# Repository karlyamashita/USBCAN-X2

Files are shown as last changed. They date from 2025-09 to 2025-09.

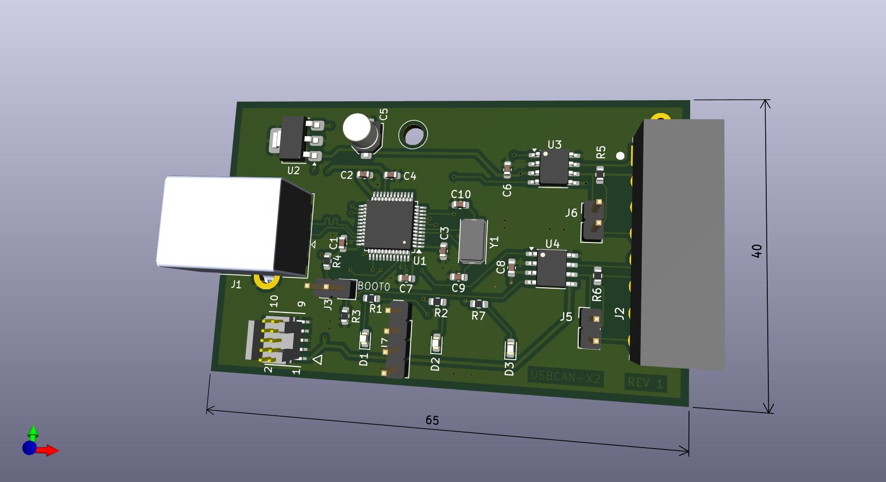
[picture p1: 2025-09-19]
Images/USBCAN-X2.jpg

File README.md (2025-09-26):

USBCAN-X2 dual CAN bus analyzer using a STM32G491CE.

The schematic and gerber files are open source.

### Description
I have been working on a [CAN Jammer](https://github.com/karlyamashita/CAN_Jammer_STM32F105RB) project and need a dual CAN bus analyzer that uses 1 STM32 microcontroller. I am finding it difficult to find a vendor that sells a dual CAN bus analyzer that uses an STM32 that is open source and does not read protect the STM32 at RDP level 2. Most vendors that i've contacted are using NXP or a Chinese brand microcontroller. 
<br><br>
Because of the difficulties of finding a dual CAN bus analyzer, I've decided to create this open source project. Since FDCAN is becoming more mainstream, I've decided to use the STM32G491CE with FDCAN controllers which meet the requirements. 

### PCB
The PBC was designed around the USBCAN-2A, matching the USB and screw terminal connector. I am hoping some Chinese manufacturer or someone local will start to manufacture this project to make readily available for purchase. Since the plastic case seems to be a dime a dozen, it will make it easier fo manufacturers to have a completely enclosed product without the need to tool for a new case, if I did create a different size PCB.

`USBCAN-2A`


### Firmware
The FW is being developed and will be open source.

### Software
CAN-X will support the USBCAN-X2 once the Firmware is done.

### Image
This is the 3D image of the USBCAN-X2

`USBCAN-X2`


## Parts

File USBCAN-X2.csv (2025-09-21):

Reference | Qty | Value | DNP | Exclude from BOM | Exclude from Board | Footprint | Datasheet | Mouser
C1,C2,C3,C4,C6,C7,C8,C11 | 8 | 0.1uF |  |  |  | Capacitor_SMD:C_0603_1608Metric | ~ | 603-C0603ZRY5V9BB104
C5 | 1 | 15uF |  |  |  | Capacitor_SMD:C_Elec_4x5.4 | ~ | 667-10SVP15M
C9,C10 | 2 | 18pF |  |  |  | Capacitor_SMD:C_0603_1608Metric | ~ | 791-RF18N180J500CT
D1 | 1 | LED Red |  |  |  | LED_SMD:LED_0603_1608Metric | ~ | 710-150060RS83000
D2 | 1 | LED Green |  |  |  | LED_SMD:LED_0603_1608Metric | ~ | 710-150060GS83000
D3 | 1 | LED Blue |  |  |  | LED_SMD:LED_0603_1608Metric | ~ | 710-150060BS83000
J1 | 1 | USB_B |  |  |  | Connector_USB:USB_B_Lumberg_2411_02_Horizontal | ~ | 523-UE27-BC54-100
J2 | 1 | Screw_Terminal_01x08 |  |  |  | Connector_Amphenol:Amphenol Anytek OQ0812510000G | ~ | 649-220110-C081A01LF
J3 | 1 | BOOT0 |  |  |  | Connector_PinHeader_2.54mm:PinHeader_1x02_P2.54mm_Vertical | ~
J4 | 1 | SWD Debug |  |  |  | Samtect:CON10_2X5_DUK_FTSH_SAI-M | ~ | 200-FTSH10501LDVKP
J5,J6 | 2 | Conn_01x02_Pin |  |  |  | Connector_PinHeader_2.54mm:PinHeader_1x02_P2.54mm_Vertical | ~
J7 | 1 | Alternative Debug Connector |  |  |  | Connector_PinHeader_2.54mm:PinHeader_1x04_P2.54mm_Vertical | ~
R1,R2,R7 | 3 | 330 |  |  |  | Resistor_SMD:R_0603_1608Metric | ~ | 774-73L2R33J
R3,R8 | 2 | 10K |  |  |  | Resistor_SMD:R_0603_1608Metric | ~ | 603-AC0603JR-7W10KL
R4 | 1 | 1k |  |  |  | Resistor_SMD:R_0603_1608Metric | ~ | 603-SR0603JR-071KL
R5,R6 | 2 | 120 |  |  |  | Resistor_SMD:R_0603_1608Metric | ~ | 603-RC0603FR-13120RL
U1 | 1 | STM32G491CETx |  |  |  | Package_QFP:LQFP-48_7x7mm_P0.5mm | https://www.st.com/resource/en/datasheet/stm32g491ce.pdf | 511-STM32G491CET6
U3,U4 | 2 | MCP2542FDxMF |  |  |  | Package_SO:SOIC-8-1EP_3.9x4.9mm_P1.27mm_EP2.29x3mm | http://ww1.microchip.com/downloads/en/DeviceDoc/MCP2542FD-4FD-MCP2542WFD-4WFD-Data-Sheet20005514B.pdf | 579-MCP2542FD-E/SN
U5 | 1 | ST730M33R |  |  |  | Package_TO_SOT_SMD:SOT-23-5 |  | ST730M33R
Y1 | 1 | 25MHz |  |  |  | Crystal:Crystal_SMD_Abracon_ABM7-2Pin_6.0x3.5mm | ~ | 815-ABM725000MHZ4T

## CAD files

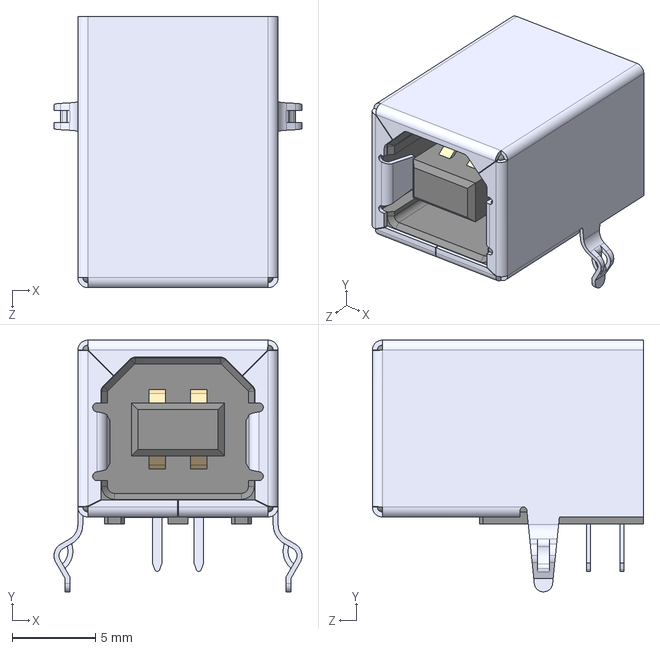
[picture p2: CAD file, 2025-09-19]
3D/UE27BC54100--3DModel-STEP-554624.STEP
14.9 x 15.1 x 16.3 mm

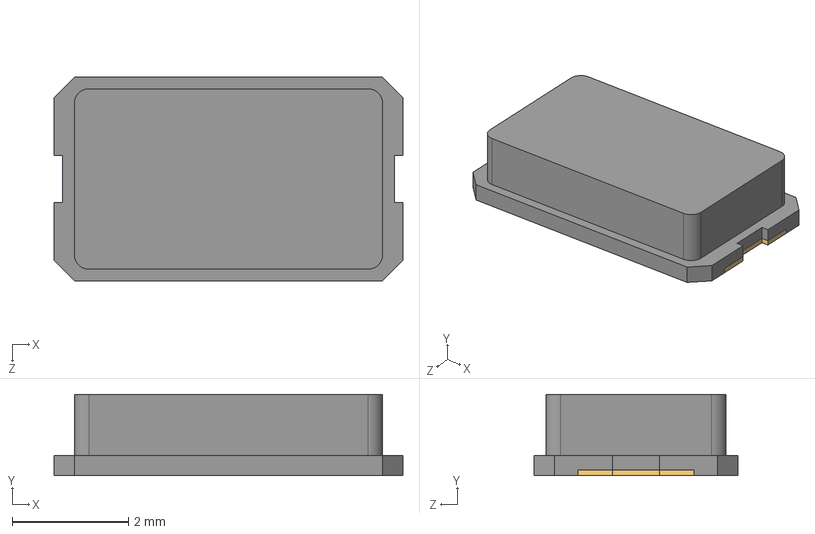
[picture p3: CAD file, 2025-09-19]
3D/ABM7-16.000MHZ-B4-T.stp
6.00 x 1.40 x 3.50 mm

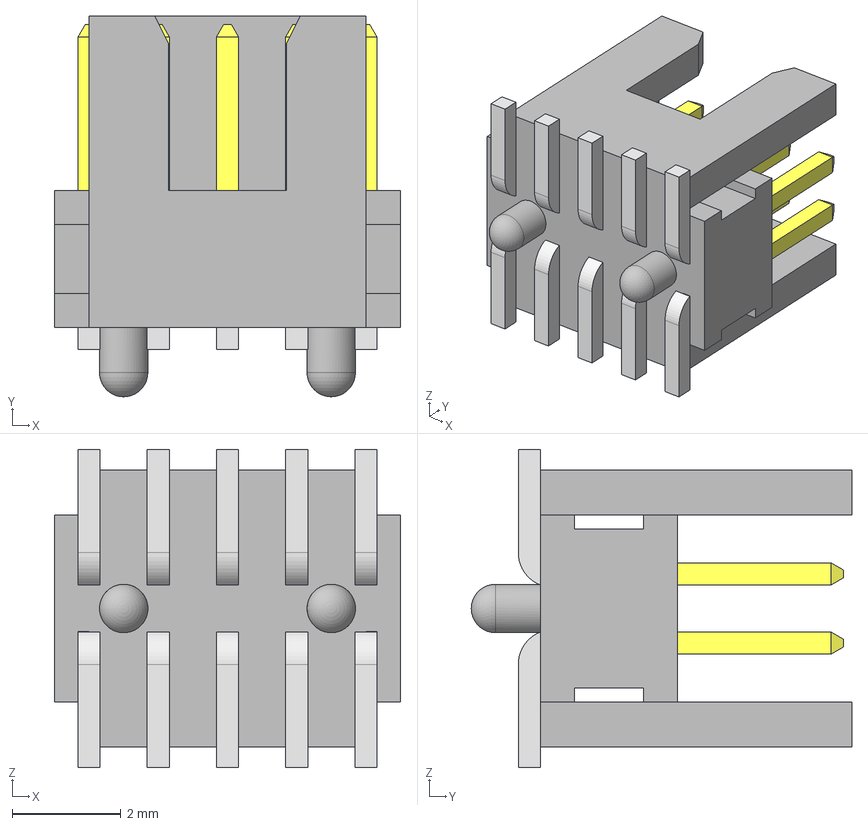
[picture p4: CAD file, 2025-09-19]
3D/FTSH-105-01-LM-DV-K-A.stp
6.35 x 6.98 x 5.84 mm
FTSH-105-01-L-DV-K-A_body
FTSH-105-01-L-DV-K_pins1
FTSH-105-01-L-DV-K_pins2

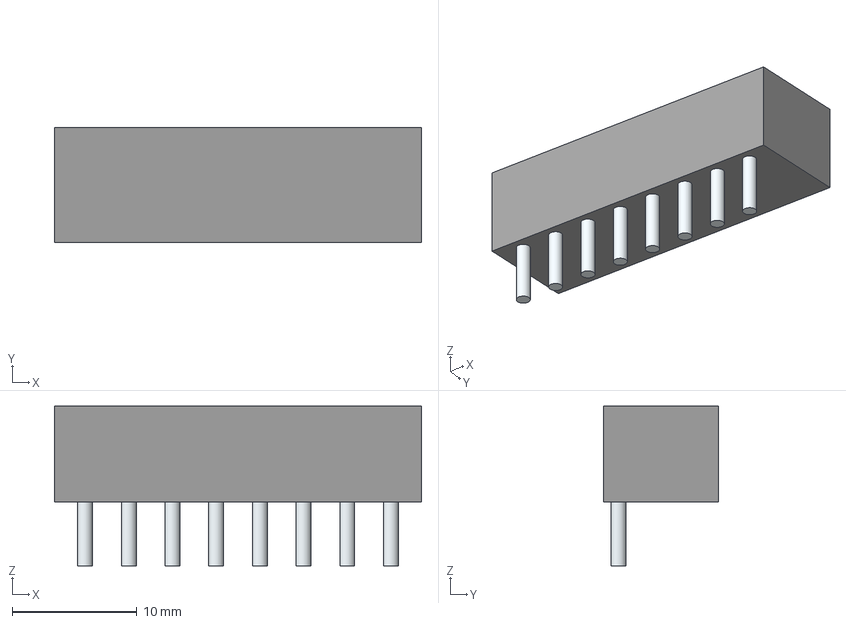
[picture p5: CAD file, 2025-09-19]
3D/OQ0812510000G.stp
29.4 x 9.20 x 12.8 mm
Leads x 8

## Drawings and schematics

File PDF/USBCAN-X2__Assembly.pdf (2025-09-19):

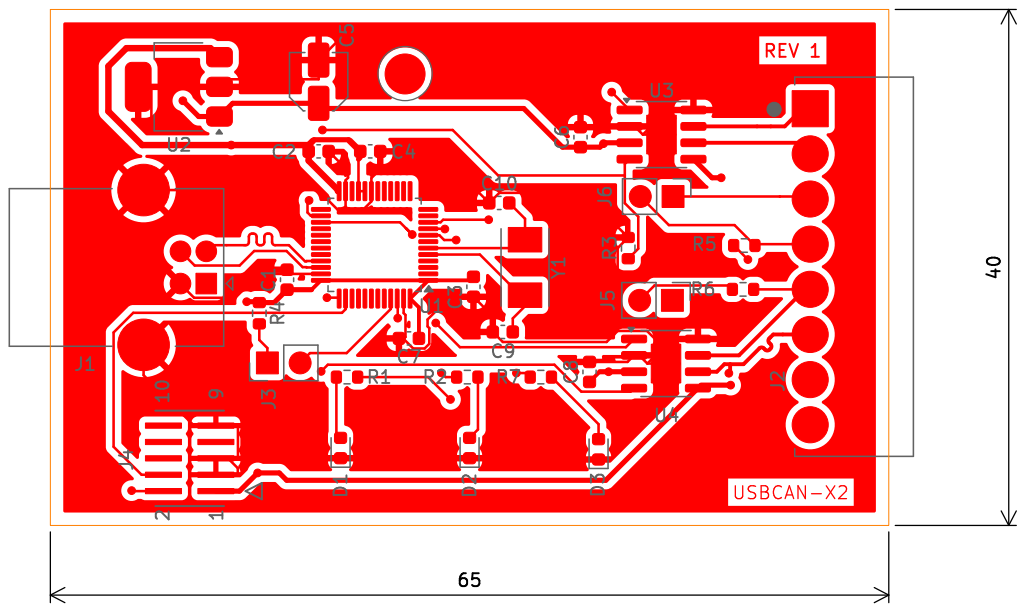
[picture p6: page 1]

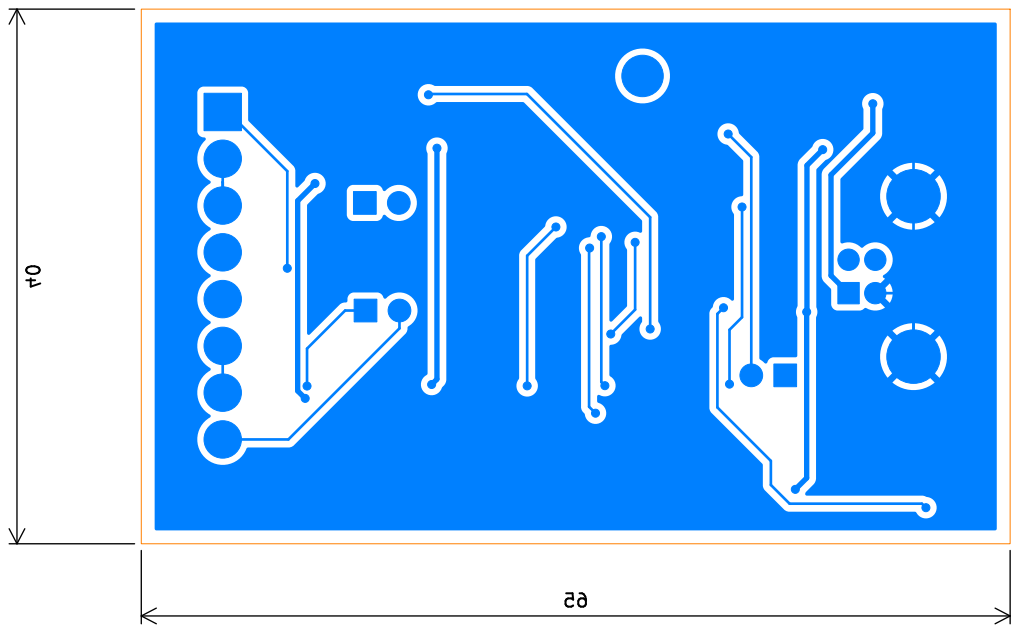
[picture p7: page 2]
D Date: 2025-09-17 KiCad; E.D.A. 9.0.4 Size: A4; Rev:; File: USBCAN-X2.kicad_pcb Sheet: Colored; BOT Copyright; Karl Yamashita Board2Pdf:; Colored; BOT -; Page 2/2

Id: /1 Title: USBCAN-X2

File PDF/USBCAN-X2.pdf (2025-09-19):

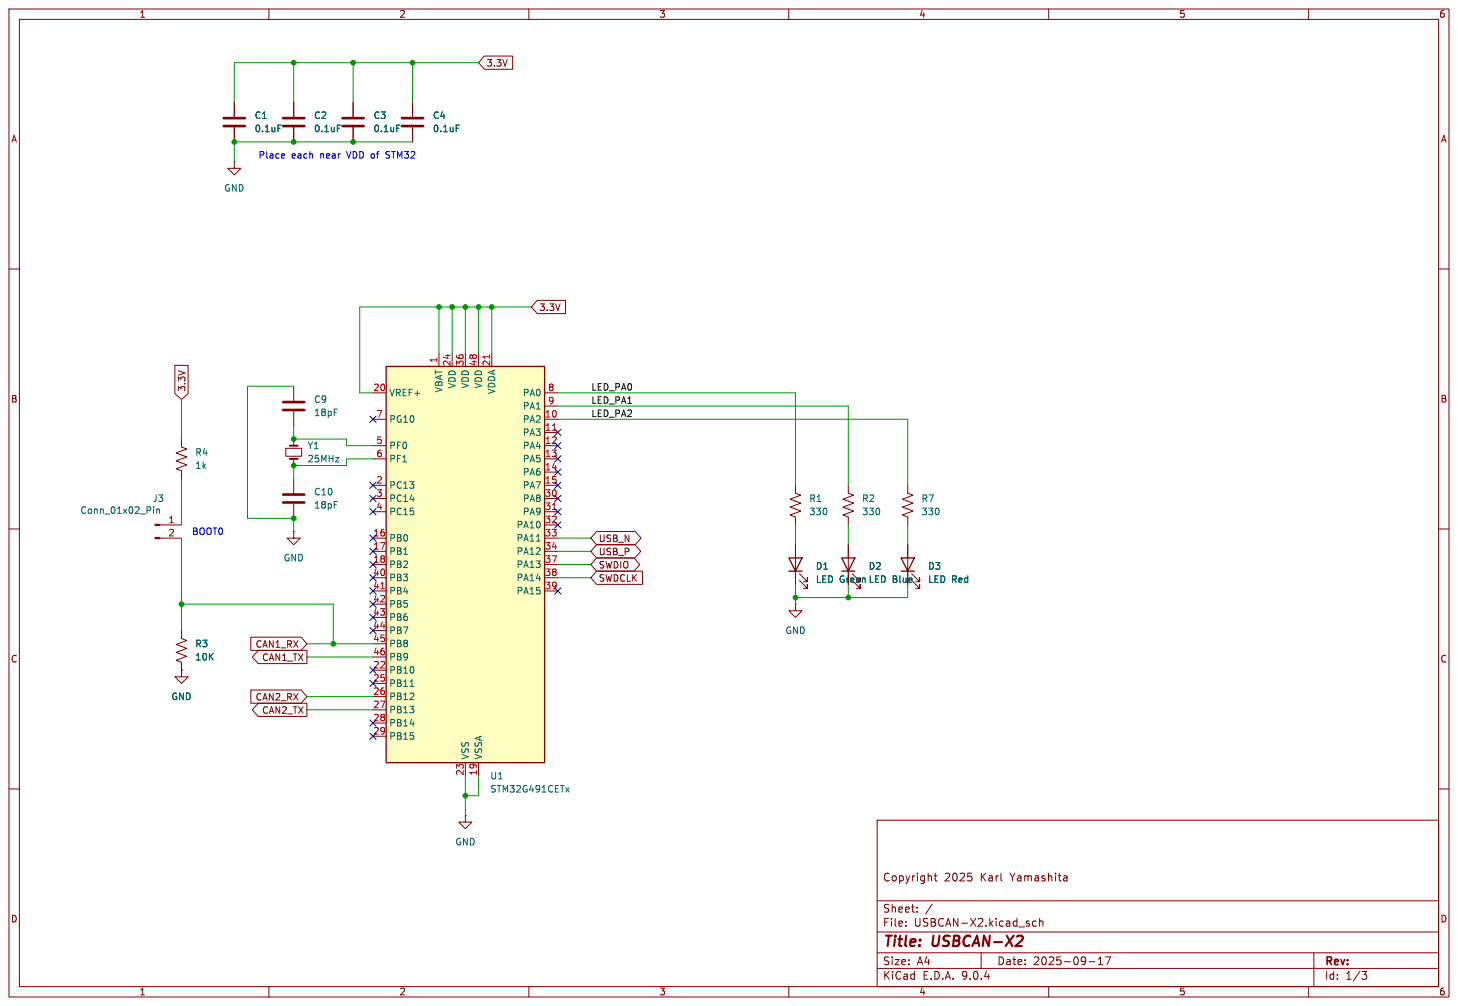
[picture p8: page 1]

1 VDD 24 VDD 36 VSS 23 VDD 48 VSSA 19 VDDA 21 PA0 8 PA1 9 PA2 10 PA3 11 PA4 12 PA5 13 PA6 14 PA7 15 PA8 30 PA9 31 PA10 32 PA11 33 PA12 34 PA13 37 PA14 38 PA15 39 U1STM32G491CETx USB_P

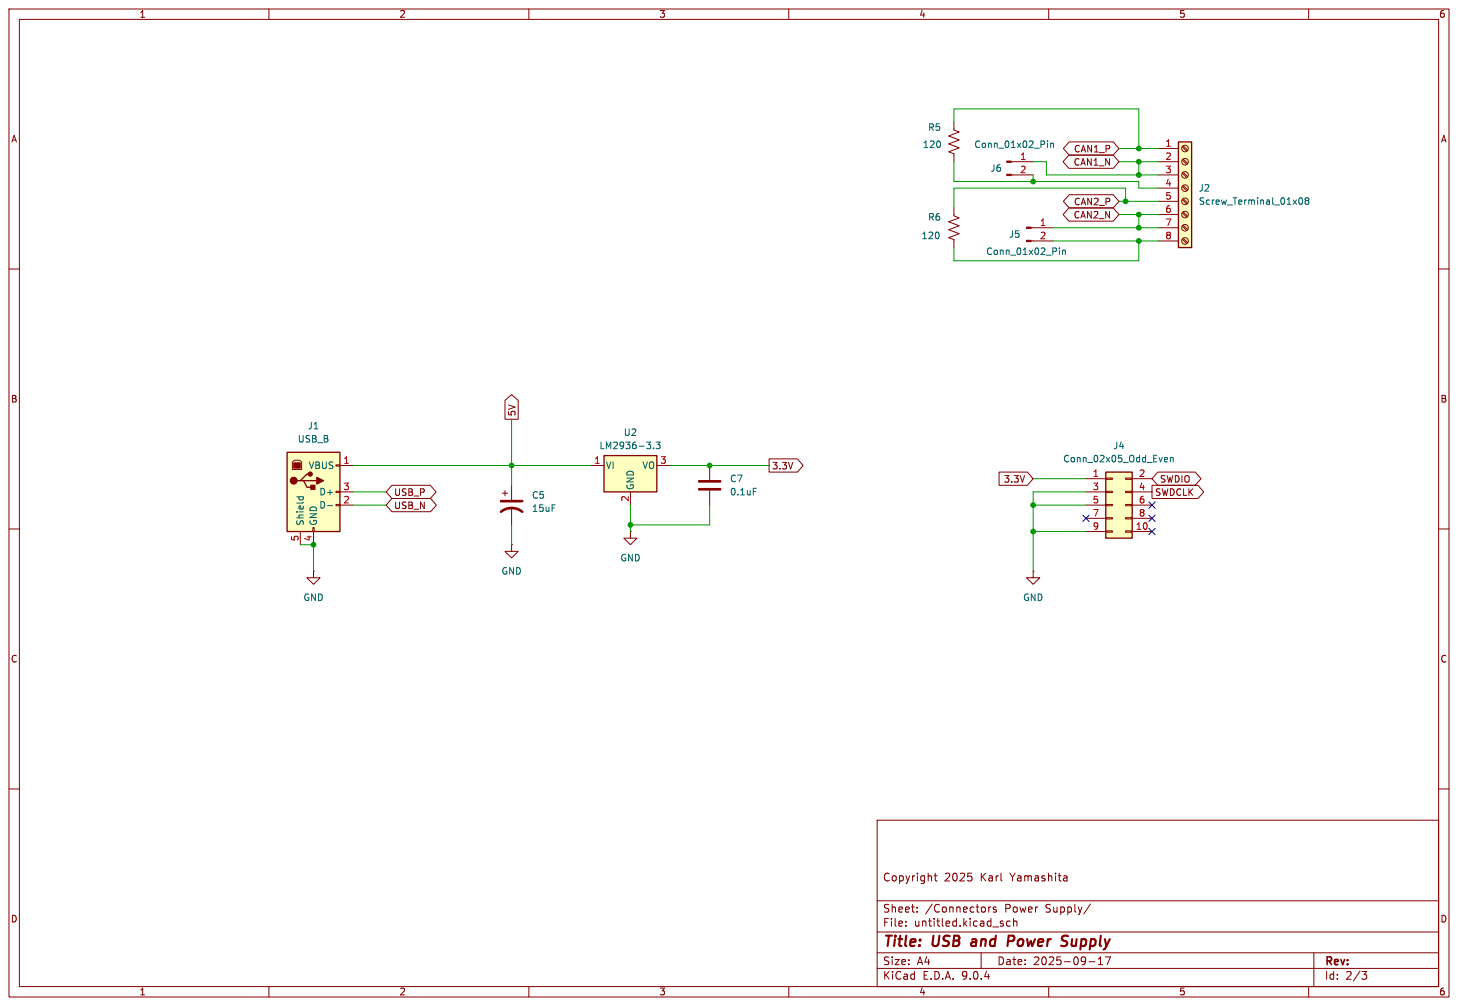
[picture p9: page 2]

Id: 2/3 Title: USB and Power Supply

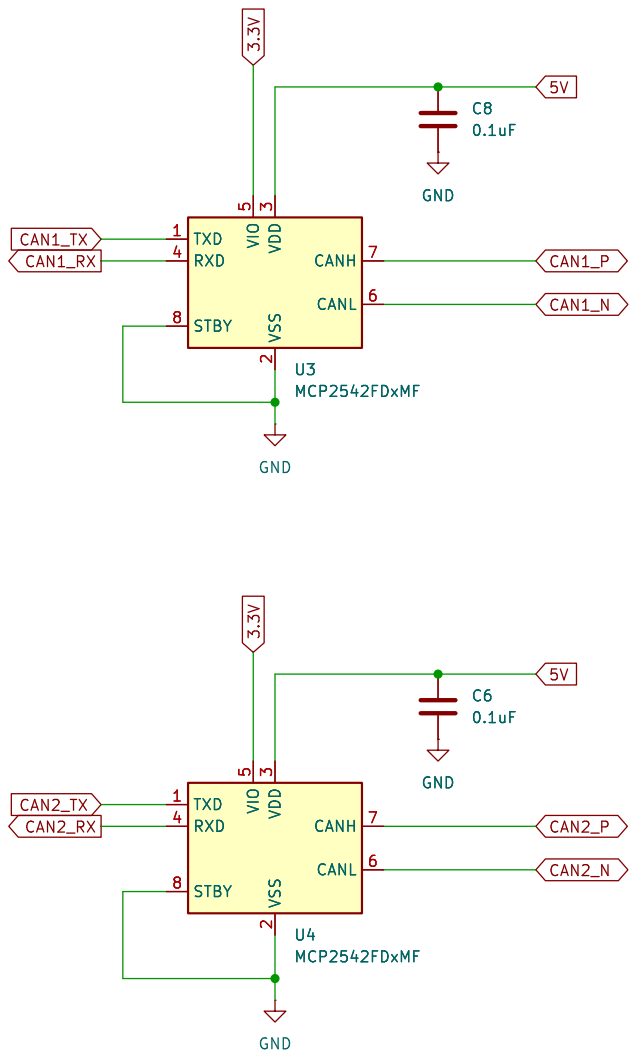
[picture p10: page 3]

2 CANH 7 CANL 6 U4 MCP2542FDxMF GND GND

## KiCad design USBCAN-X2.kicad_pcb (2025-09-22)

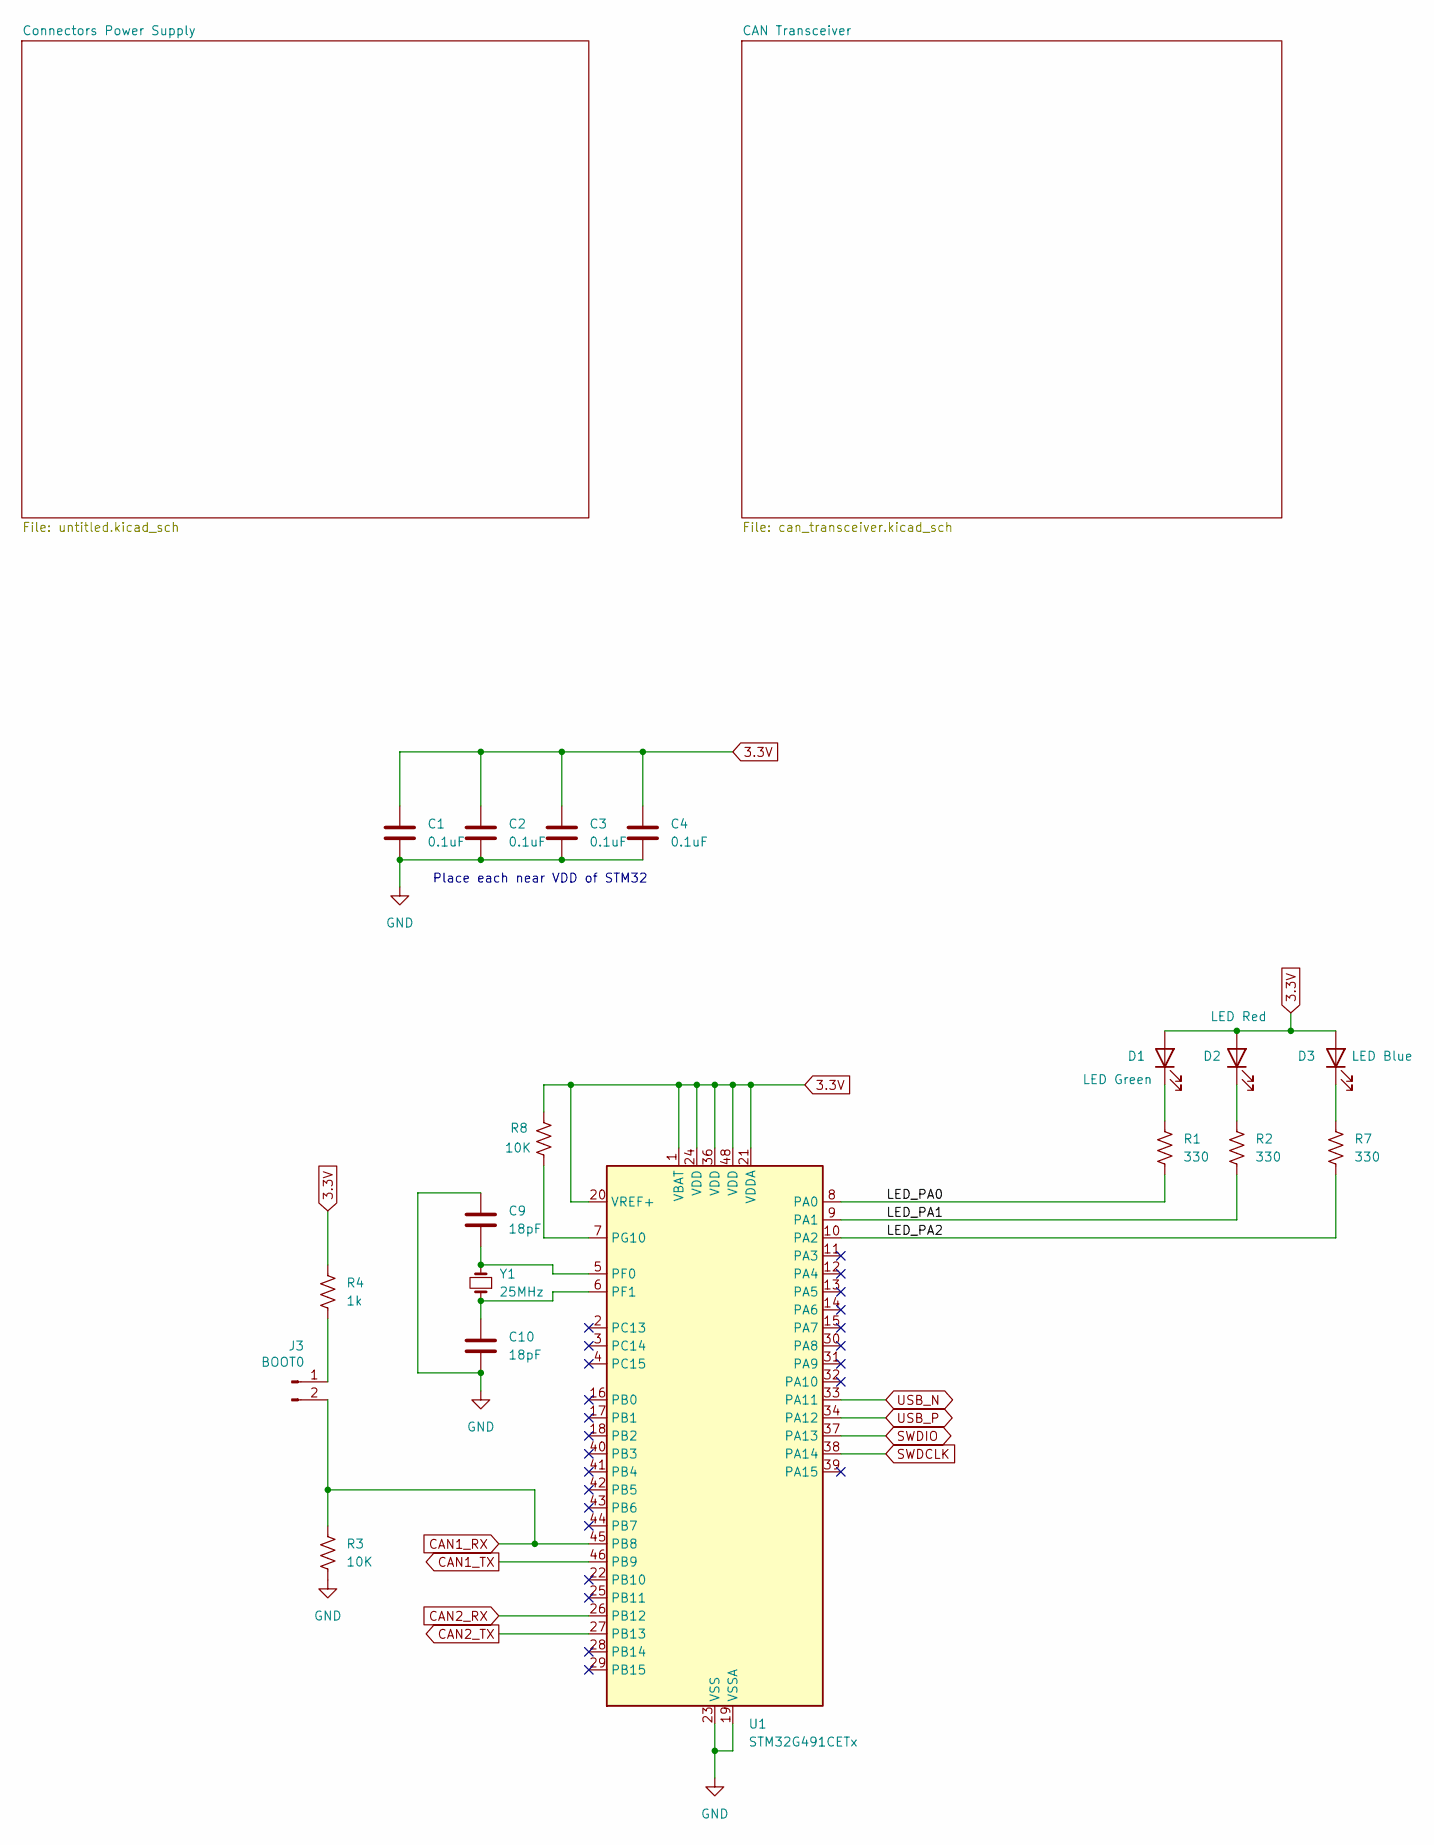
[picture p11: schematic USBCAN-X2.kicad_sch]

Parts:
C1, C2, C3, C4: 0.1uF; C_0603_1608Metric; Mouser 603-C0603ZRY5V9BB104
C9, C10: 18pF; C_0603_1608Metric; Mouser 791-RF18N180J500CT
D1: LED Red; LED_0603_1608Metric; Mouser 710-150060RS83000
D2: LED Green; LED_0603_1608Metric; Mouser 710-150060GS83000
D3: LED Blue; LED_0603_1608Metric; Mouser 710-150060BS83000
J3: BOOT0; PinHeader_1x02_P2.54mm_Vertical
R1, R2, R7: 330; R_0603_1608Metric; Mouser 774-73L2R33J
R3, R8: 10K; R_0603_1608Metric; Mouser 603-AC0603JR-7W10KL
R4: 1k; R_0603_1608Metric; Mouser 603-SR0603JR-071KL
U1: STM32G491CETx; LQFP-48_7x7mm_P0.5mm; Mouser 511-STM32G491CET6
Y1: 25MHz; Crystal_SMD_Abracon_ABM7-2Pin_6.0x3.5mm; Mouser 815-ABM725000MHZ4T

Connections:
3.3V: C1.1, C2.1, C3.1, C4.1, D1.2 (A), D2.2 (A), D3.2 (A), R4.1, R8.1, U1.1 (VBAT), U1.20 (VREF+), U1.21 (VDDA), U1.24 (VDD), U1.36 (VDD), U1.48 (VDD); also elsewhere on the board
/LED_PA0: R1.2, U1.8 (PA0)
/LED_PA1: R2.2, U1.9 (PA1)
/LED_PA2: R7.2, U1.10 (PA2)
CAN1_RX: J3.2, R3.1, U1.45 (PB8); also elsewhere on the board
CAN1_TX: U1.46 (PB9); also elsewhere on the board
CAN2_RX: U1.26 (PB12); also elsewhere on the board
CAN2_TX: U1.27 (PB13); also elsewhere on the board
GND: C1.2, C2.2, C3.2, C4.2, C9.1, C10.2, R3.2, U1.19 (VSSA), U1.23 (VSS), U1.35 (VSS), U1.47 (VSS); also elsewhere on the board
unnamed: D1.1 (K), R1.1
unnamed: D2.1 (K), R2.1
unnamed: D3.1 (K), R7.1
unnamed: J3.1, R4.2
unnamed: C9.2, U1.5 (PF0), Y1.2
unnamed: C10.1, U1.6 (PF1), Y1.1
unnamed: R8.2, U1.7 (PG10)
SWDCLK: U1.38 (PA14); also elsewhere on the board
SWDIO: U1.37 (PA13); also elsewhere on the board
USB_N: U1.33 (PA11); also elsewhere on the board
USB_P: U1.34 (PA12); also elsewhere on the board

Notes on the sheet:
Place each near VDD of STM32

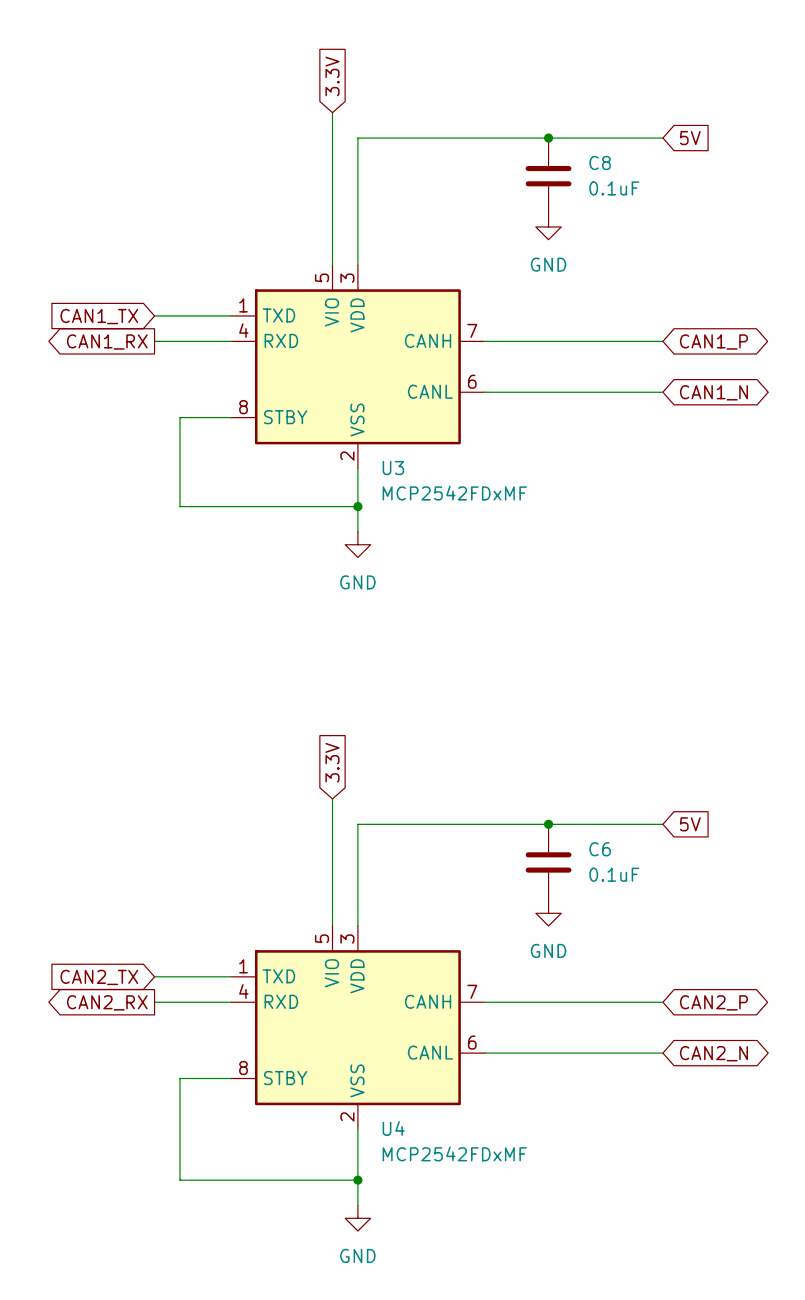
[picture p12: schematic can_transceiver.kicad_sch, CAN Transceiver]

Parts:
C6, C8: 0.1uF; C_0603_1608Metric; Mouser 603-C0603ZRY5V9BB104
U3, U4: MCP2542FDxMF; SOIC-8-1EP_3.9x4.9mm_P1.27mm_EP2.29x3mm; Mouser 579-MCP2542FD-E/SN

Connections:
3.3V: U3.5 (VIO), U4.5 (VIO); also elsewhere on the board
5V: C6.1, C8.1, U3.3 (VDD), U4.3 (VDD); also elsewhere on the board
CAN1_N: U3.6 (CANL); also elsewhere on the board
CAN1_P: U3.7 (CANH); also elsewhere on the board
CAN1_RX: U3.4 (RXD); also elsewhere on the board
CAN1_TX: U3.1 (TXD); also elsewhere on the board
CAN2_N: U4.6 (CANL); also elsewhere on the board
CAN2_P: U4.7 (CANH); also elsewhere on the board
CAN2_RX: U4.4 (RXD); also elsewhere on the board
CAN2_TX: U4.1 (TXD); also elsewhere on the board
GND: C6.2, C8.2, U3.2 (VSS), U3.8 (STBY), U3.9 (VSS), U4.2 (VSS), U4.8 (STBY), U4.9 (VSS); also elsewhere on the board

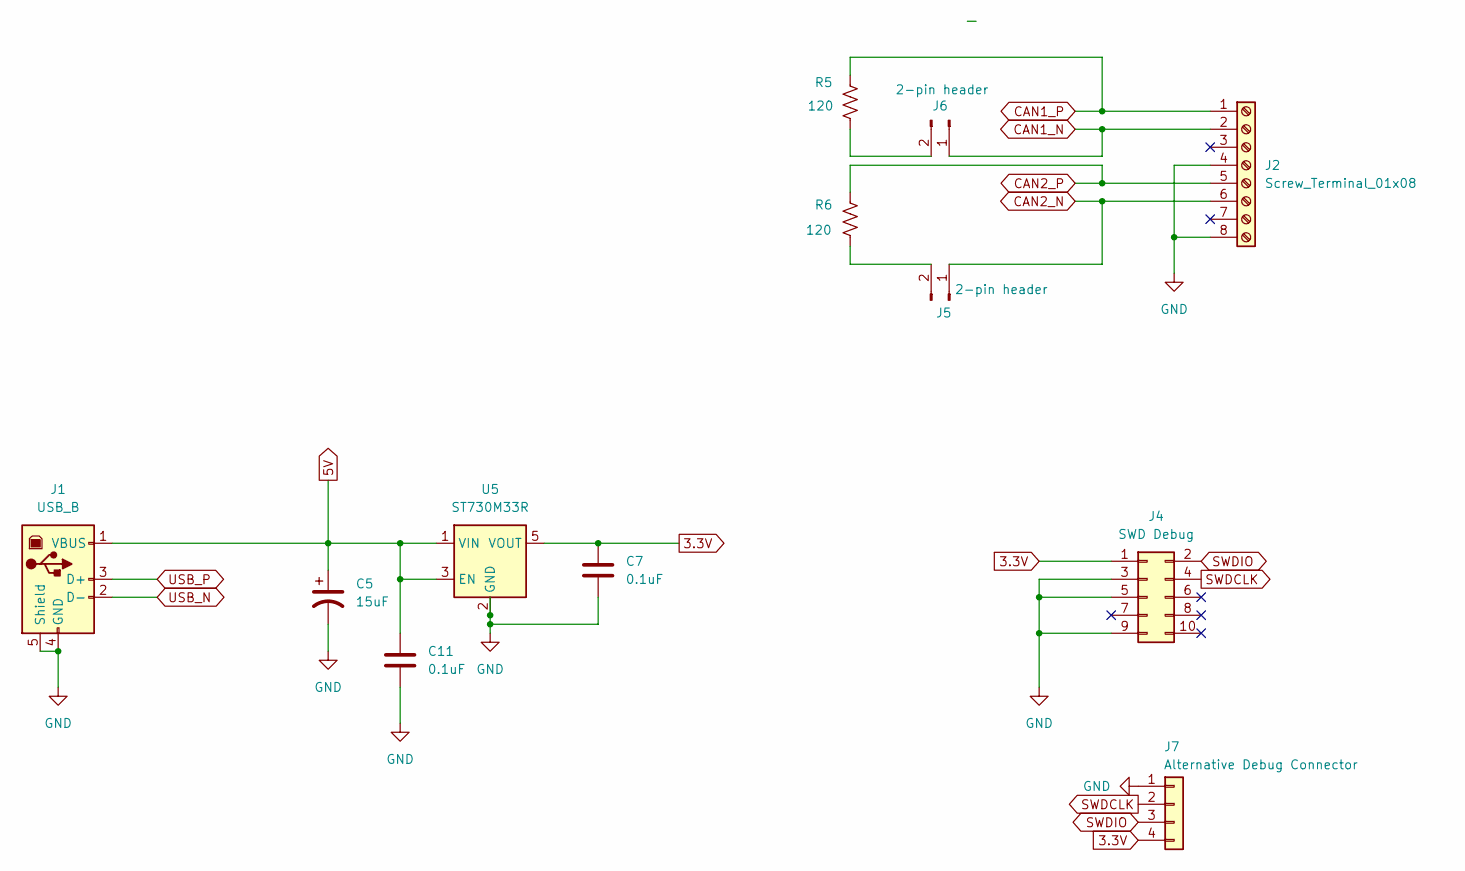
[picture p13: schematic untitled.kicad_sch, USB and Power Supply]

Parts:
C5: 15uF; C_Elec_4x5.4; Mouser 667-10SVP15M
C7, C11: 0.1uF; C_0603_1608Metric; Mouser 603-C0603ZRY5V9BB104
J1: USB_B; USB_B_Lumberg_2411_02_Horizontal; Mouser 523-UE27-BC54-100
J2: Screw_Terminal_01x08; Amphenol Anytek OQ0812510000G; Mouser 649-220110-C081A01LF
J4: SWD Debug; CON10_2X5_DUK_FTSH_SAI-M; Mouser 200-FTSH10501LDVKP
J5, J6: 2-pin header; PinHeader_1x02_P2.54mm_Vertical
J7: Alternative Debug Connector; PinHeader_1x04_P2.54mm_Vertical
R5, R6: 120; R_0603_1608Metric; Mouser 603-RC0603FR-13120RL
U5: ST730M33R; SOT-23-5; Mouser ST730M33R

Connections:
3.3V: C7.1, J4.1, J7.4, U5.5 (VOUT); also elsewhere on the board
5V: C5.1, C11.1, J1.1 (VBUS), U5.1 (VIN), U5.3 (EN); also elsewhere on the board
CAN1_N: J2.2, J6.1; also elsewhere on the board
CAN1_P: J2.1, R5.1; also elsewhere on the board
CAN2_N: J2.6, J5.1; also elsewhere on the board
CAN2_P: J2.5, R6.1; also elsewhere on the board
GND: C5.2, C7.2, C11.2, J1.4 (GND), J1.5 (Shield), J2.4, J2.8, J4.3, J4.5, J4.9, J7.1, U5.2 (GND); also elsewhere on the board
unnamed: J5.2, R6.2
unnamed: J6.2, R5.2
SWDCLK: J4.4, J7.2; also elsewhere on the board
SWDIO: J4.2, J7.3; also elsewhere on the board
USB_N: J1.2 (D-); also elsewhere on the board
USB_P: J1.3 (D+); also elsewhere on the board

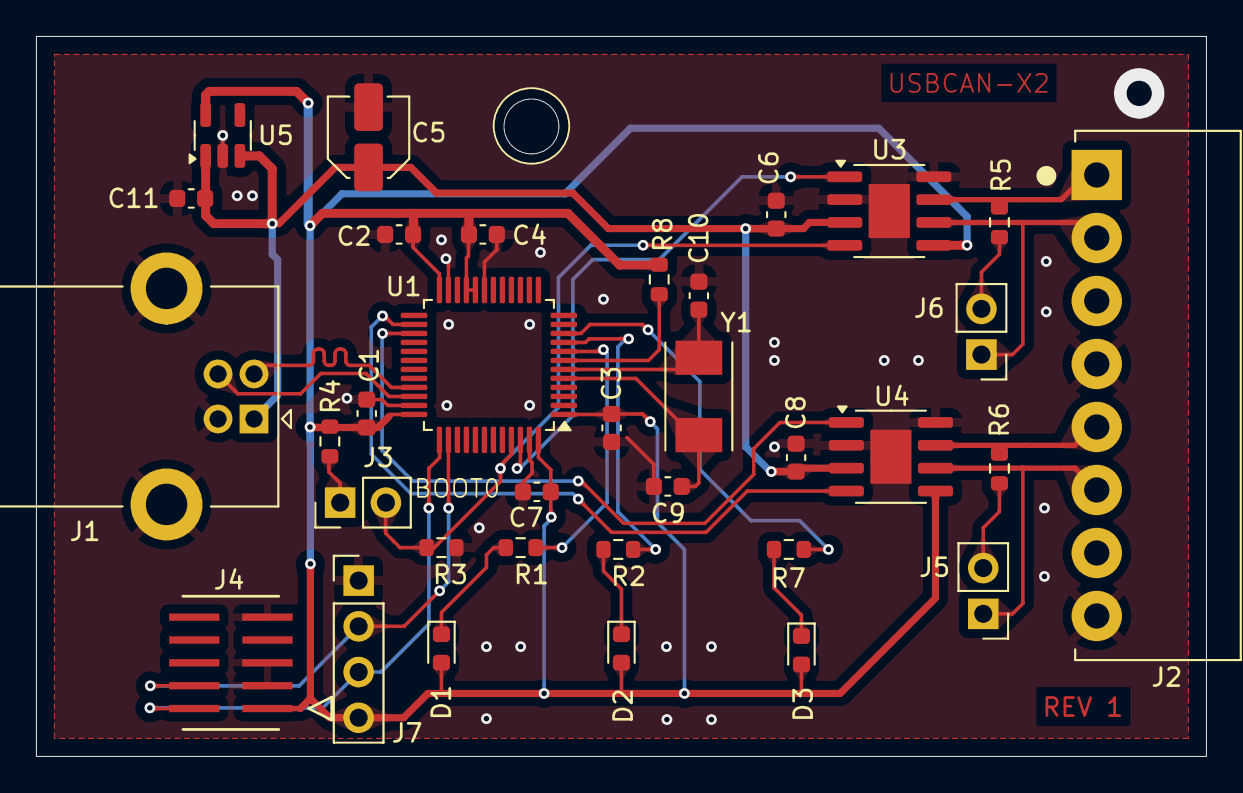
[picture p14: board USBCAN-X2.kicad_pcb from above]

Board: 2 copper layers, 65.0 x 40.0 mm, 34 parts (0 on the bottom side), 27 nets.

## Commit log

2025-09-18 Init commit. Board outline is a mockup until I get actual dimensions.
    [USBCAN-X2.kicad_pcb, USBCAN-X2.kicad_sch, can_transceiver.kicad_sch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]
2025-09-19 Created PDF's
    [USBCAN-X2-B_Cu.gbr, USBCAN-X2-B_Mask.gbr, USBCAN-X2-B_Paste.gbr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]
2025-09-19 Moved CAN transceiver and jumper pins. Rerouted tracks. Added 3D models to 3D folder as they are linked and not embedded.
    [ABM7-16.000MHZ-B4-T.stp, FTSH-105-01-LM-DV-K-A.stp, OQ0812510000G.stp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]
2025-09-19 Added an alternative 4-pin debug header
    [USBCAN-X2-B_Cu.gbr, USBCAN-X2-B_Mask.gbr, USBCAN-X2-B_Paste.gbr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]
2025-09-21 Add pull-up to NRST
    [USBCAN-X2-B_Cu.gbr, USBCAN-X2-B_Mask.gbr, USBCAN-X2-B_Paste.gbr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]
2025-09-22 Clean some tracks up.
    [USBCAN-X2.kicad_pcb, USBCAN-X2.kicad_sch, untitled.kicad_sch]

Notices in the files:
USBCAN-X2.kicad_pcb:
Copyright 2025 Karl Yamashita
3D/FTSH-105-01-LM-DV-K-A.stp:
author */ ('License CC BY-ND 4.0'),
